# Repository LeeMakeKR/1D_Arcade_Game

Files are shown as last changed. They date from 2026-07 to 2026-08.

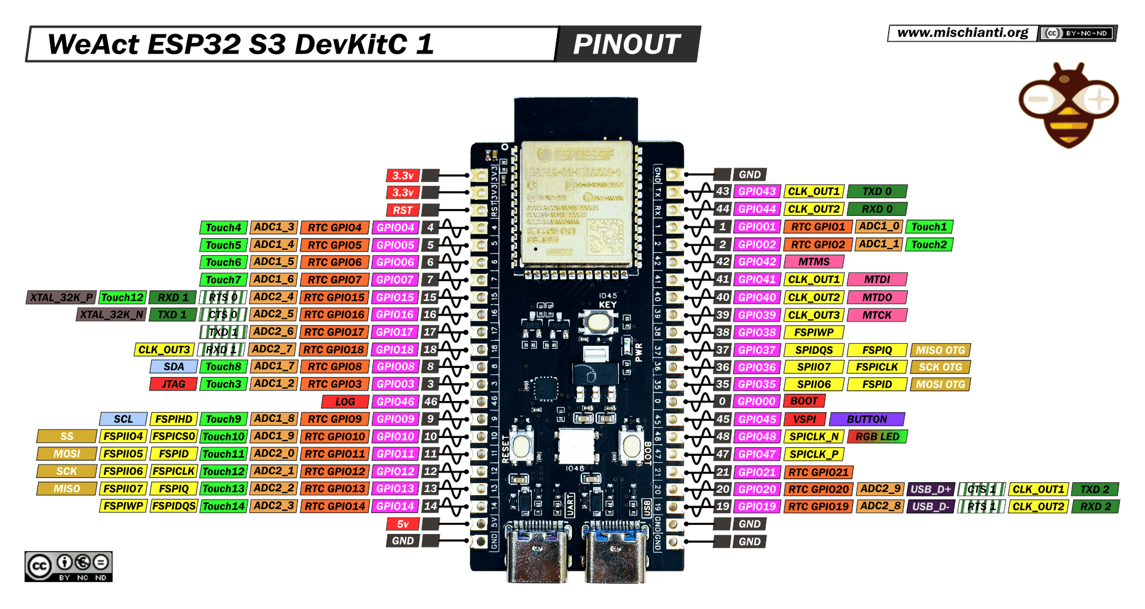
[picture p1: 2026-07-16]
pics/WeAct-esp32-S3-DevKitC-1-pinout-mischianti.png

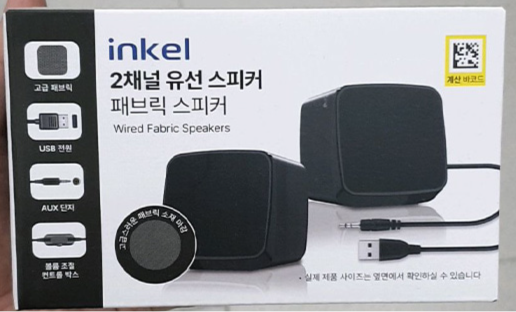
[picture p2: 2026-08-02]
pics/스크린샷 2026-08-02 133538.png

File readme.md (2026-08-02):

WS2815 line LED 를 사용한 1D arcade 게임기 제작 프로젝트

개요

3m 길이의 WS2815 라인 LED 172칸을 화면 삼아, 위치와 색만으로 게임을 표현하는 1차원 아케이드 게임기다
ESP32-S3 한 장에 아케이드 스위치 4개와 ST7735 LCD, I2S 앰프를 물려 입력·점수판·효과음을 함께 처리한다.
같은 펌웨어를 올린 보드 두 대를 ESP-NOW로 연결하면 2인 대전이 되고
수록 게임은 SNAKE INVADER / SOLO PONG / DUEL PONG 세 가지다.

[입력]

- 버튼1: GPIO7 - WS2815 LED 가 결합된 아케이드 스위치
- 버튼2: GPIO15 - WS2815 LED 가 결합된 아케이드 스위치
- 버튼3: GPIO16 - WS2815 LED 가 결합된 아케이드 스위치
- 버튼4: GPIO17 - WS2815 LED 가 결합된 아케이드 스위치
- 버튼5: GPIO18 - 토글 스위치, 선택에 따라 1p/2p 전환. 

미구현
- 조이스틱 X축 (아날로그, ADC1_CH3, 하드웨어 고정): GPIO4
- 조이스틱 Y축 (아날로그, ADC1_CH4, 하드웨어 고정): GPIO5
- 조이스틱 클릭 스위치 (디지털 입력): GPIO6

[출력]

- WS2815 데이터(DI): GPIO8
- WS2815 백업 데이터(BI): GPIO 연결 불필요 — 스트립 입구에서 GND에 연결(플로팅 금지)
- ST7735 TFT LCD (128x160, 4-wire SPI): RS(=DC) GPIO9, CS GPIO10(FSPI 하드웨어 기본 CS0), SDA(=MOSI) GPIO11(FSPI 하드웨어 기본 핀), CLK(=SCLK) GPIO12(FSPI 하드웨어 기본 핀), RST GPIO14, VCC 3.3V, GND GND
  - 모듈에 백라이트 핀(BLK/LED)이 따로 나와 있는 버전이면 3.3V에 연결한다.
  - 핀이 7개(VCC/GND/CLK/SDA/RS/RST/CS)뿐인 보드는 백라이트가 내부에서 VCC에 물려 있다.
  - VCC는 3.3V 권장. 레귤레이터가 실장된 모듈이라 5V도 받지만, 로직 레벨 시프터가 없는 모듈에 5V를 넣으면 3.3V 신호가 불안정해질 수 있다.
- I2S MAX98357A (앰프): BCLK GPIO42, LRCLK(WS) GPIO41, DOUT GPIO40
- 보드 간 통신: ESP-NOW 무선

핀아웃 다이어그램 (WeAct ESP32-S3 N16R8 DevKitC-1, mischianti 핀아웃 이미지 배치 기준)

```text
                                                     ┌─[ANT]──┐
                                      3V3            ●──┤        ├──●  GND
                                      3V3            ●──┤        ├──●  GPIO43         → (USB-UART TXD0, 사용금지)
                                      RST            ●──┤        ├──●  GPIO44         → (USB-UART RXD0, 사용금지)
           IN: 조이스틱 X (ADC1_CH3)  GPIO4          ●──┤        ├──●  GPIO1          → (예비 핀)
           IN: 조이스틱 Y (ADC1_CH4)  GPIO5          ●──┤        ├──●  GPIO2          → (예비 핀)
            IN: 조이스틱 클릭 스위치  GPIO6          ●──┤        ├──●  GPIO42         → OUT: I2S BCLK
                           IN: 버튼1  GPIO7          ●──┤        ├──●  GPIO41         → OUT: I2S LRCLK(WS)
                           IN: 버튼2  GPIO15         ●──┤        ├──●  GPIO40         → OUT: I2S DOUT
                           IN: 버튼3  GPIO16         ●──┤        ├──●  GPIO39         → (JTAG 예비핀, 미사용)
                           IN: 버튼4  GPIO17         ●──┤        ├──●  GPIO38         → (옥탈 PSRAM 내부용, 사용금지)
                           IN: 버튼5  GPIO18         ●──┤        ├──●  GPIO37         → (옥탈 PSRAM 내부용, 사용금지)
                    OUT: WS2815 DATA  GPIO8          ●──┤        ├──●  GPIO36         → (옥탈 PSRAM 내부용, 사용금지)
             (스트랩핀/JTAG, 미사용)  GPIO3          ●──┤        ├──●  GPIO35         → (옥탈 PSRAM 내부용, 사용금지)
                  (스트랩핀, 미사용)  GPIO46         ●──┤        ├──●  GPIO0          → (스트랩핀/BOOT, 미사용)
                     OUT: LCD RS(DC)  GPIO9          ●──┤        ├──●  GPIO45         → (스트랩핀/VDD_SPI, 미사용)
         OUT: LCD CS (FSPI 기본 CS0)  GPIO10         ●──┤        ├──●  GPIO48         → (온보드 WS2812 RGB LED 전용)
     OUT: LCD SDA/MOSI (FSPI 기본핀)  GPIO11         ●──┤        ├──●  GPIO47         → (예비 핀)
     OUT: LCD CLK/SCLK (FSPI 기본핀)  GPIO12         ●──┤        ├──●  GPIO21         → (예비 핀)
 (예비, FSPI MISO 기본핀·LCD 미사용)  GPIO13         ●──┤        ├──●  GPIO20         → (USB D-, 사용금지)
                        OUT: LCD RST  GPIO14         ●──┤        ├──●  GPIO19         → (USB D+, 사용금지)
                                      5V             ●──┤         ├──●  GND
                                      GND            ●──┤        ├──●  GND
                                                     └[UART]──[USB]┘
```

핀 선택 이유 / 특정 핀 사용 주의사항

1. 이 보드(N16R8)는 16MB 플래시 + 8MB 옥탈(Octal) PSRAM 구성으로, PSRAM용 추가 데이터 라인과 DQS 스트로브가 GPIO33~37에 내부 배선되어 있음. GPIO33/34는 아예 헤더로 나오지 않고, GPIO35/36/37은 헤더에 노출되어 있지만 실제로는 PSRAM 전용이라 GPIO로 재사용하면 PSRAM 접근이 깨져 보드가 멎을 수 있음 → 세 핀 모두 사용 금지. 같은 그룹에 인접한 GPIO38도 안전을 위해 예비로 비워둠.
2. 조이스틱 아날로그 입력(X/Y)은 ADC1 전용 핀(GPIO4/5)에 배치. ESP32-S3도 클래식 ESP32와 동일하게 Wi-Fi 활성 시 ADC2 정확도/사용 제한 이슈가 있어 ADC1이 안전함. 같은 조이스틱 신호인 클릭 스위치(GPIO6)도 바로 옆 핀에 배치.
3. GPIO0/3/45/46은 부팅 모드를 결정하는 스트랩핀(GPIO0: BOOT, GPIO3: JTAG 신호 소스 선택, GPIO45: VDD_SPI 전압 선택, GPIO46: ROM 메시지 출력 제어). 외부 소자가 부팅 순간 이 핀들의 전압을 강제로 바꾸면 오동작할 수 있어 미사용으로 비워둠.
4. GPIO43/44는 보드 내장 USB-UART 브릿지(별도 USB-C "UART" 포트)가 사용하는 UART0(TXD0/RXD0) 고정 핀이라 시리얼 모니터/펌웨어 업로드 용도로 남겨두고 다른 용도로 쓰지 않음. GPIO19/20은 칩 내장 네이티브 USB(D-/D+)로 "USB" 포트에 연결되어 있어 마찬가지로 비워둠.
5. GPIO48은 보드에 실장된 온보드 WS2812 RGB LED 전용 데이터 핀이라 외부 신호 용도로 재사용하지 않음. 외부 WS2815 라인은 별도 핀(GPIO8)을 사용.
6. LCD는 SCLK(GPIO12)/MOSI(GPIO11)/CS(GPIO10)를 FSPI(ESP32-S3 기본 SPI) 하드웨어 기본 핀 그대로 사용하는 것을 최우선으로 함(라이브러리 하드웨어 SPI 그대로 사용 가능하고, CS까지 기본 핀에 맞출 수 있어 이전 클래식 ESP32 설계보다 배선이 더 단순함). DC/RST는 자유 GPIO라 이 블록 양옆의 GPIO9/14에 배치했으며, FSPI MISO 기본핀(GPIO13)은 LCD가 읽기 신호를 쓰지 않아 예비 핀으로 남김. ST7735의 RS/SDA/CLK는 각각 DC/MOSI/SCLK와 같은 신호임. ST7735는 128x160x16bit라 전체 화면 한 장이 40KB이므로, SPI 클럭을 하드웨어 SPI 최대치(27~40MHz)로 올리고 화면 전체를 매번 다시 그리는 대신 바뀐 영역만 갱신하는 편이 좋음.
7. 버튼 5개(GPIO7/15/16/17/18)와 조이스틱(GPIO4/5/6)은 보드 좌측 헤더에서 RST 이후로 물리적으로 연속된 핀에 몰아서 배치해 배선을 단순화. 기능적 제약이 없는 핀이라 인접 배치를 우선 적용.
8. UART2(GPIO1/2)와 I2S(GPIO42/41/40)는 클래식 ESP32와 달리 ESP32-S3에서는 GPIO 매트릭스로 완전히 자유롭게 재배치 가능한 주변장치라 하드웨어로 고정된 핀이 아님. 남은 핀 중 보드 우측 헤더에서 서로 인접한 자리를 골라 배치했을 뿐 반드시 이 핀이어야 하는 것은 아님.
9. WS2815는 타이밍에 민감하므로 다른 기능과 공유하지 않는 GPIO8에 단독 배치 권장.
10. GPIO39(JTAG 예비), GPIO47, GPIO21은 하드웨어 제약이 없는 예비 핀으로 남겨둠.
12. 아두이노에서 컴파일 시 확인할 것.
- ESP32-S3 보드 선택
- FLASH SIZE: 16MB
- Partition Scheme: HUGE APP
- UPLOAD SPEED: 921600 으로 하면 실패하는 경우 있음. 115200으로. 

효과음 제작은 
https://sfxr.me/
에서 했으며 sounds.md 문서에 정리해 두었다.

BOM

WS2815
https://aliexpress.com/item/4001331197520.html
[3M 60 IP67]
- 1미터당 60개의 LED 가 배치되어 있으며 WS2815칩을 사용하여 12v를 그대로 사용할 수 있다. 
WS2812 는 테스트 결과 끝단 전압 강하로 추가로 전선 연결이 필요하여 제작이 번거롭다
3미터 총 180개의 LED를 사용하며, 스위치용으로 8개를 절단해 LED 스트립에는 172개를 사용한다

항공잭
https://aliexpress.com/item/1005008859055554.html
GX12, 5Pin, 5Sets (Male Female)
- 2pin 을 구매해도 됨
- 최초 통신 연결용으로 5핀을 사용했으나, ESPNOW 로 통신하게 되어 필요가 없어졌다. 전원공급 2선만 사용해도 충분하다

MAX98357A 사운드 모듈
https://aliexpress.com/item/1005012452360614.html

기타
xh connectors, 
wires

m3 insert nuts, bolts

speakers
-다이소에서 구매한 스피커를 사용했다

power jack
https://aliexpress.com/item/1005007327459848.html

power switch
https://ko.aliexpress.com/item/1005006151890626.html

arcade switch
구매했던 제품은 링크가 사라져 최대한 비슷한 제품을 링크한다
지름 30MM 에 투명한 제품이면 거의 사용 가능
https://ko.aliexpress.com/item/1005008769355244.html

tft lcd
https://aliexpress.com/item/1005012439751456.html
-ST7735 128x160 SPI 모듈 사용
이것도 링크가 사라져 비슷한 제품을 링크한 것인데 이런 류의 LCD 모듈은 제품마다 약간씩 화면 표시가 달라지는 경우가 있다. 
RED TAB, GREEN TAB, BLUE TAB 등으로 구분되며, RED TAB 이 가장 일반적이다.
화면이 이상하게 표시되면 TAB 색상을 확인하고, 라이브러리에서 해당 TAB에 맞는 초기화 코드를 사용해야 한다.

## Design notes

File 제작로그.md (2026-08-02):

# 제작 로그

## 2026-07-25

- 1P/2P 통신을 ESP-NOW로 변경
- LED를 WS2815로 변경
- 이에 따라 핀아웃 변경

## 2026-07-26

- 테스트 코드 정리

## 2026-07-30

### 사운드 테스트

sfxr로 만든 사운드 파라미터를 이용해 바로 재생할 수 있는지 검토해 보니,
미리 렌더링을 해서 PSRAM에 저장해 두고 재생하는 것도 가능함을 확인.

#### 부팅 시 프리렌더 PCM → PSRAM

- sfxr 파라미터를 부팅 때 한 번만 PCM으로 렌더 → PSRAM에 저장
- 런타임엔 믹서가 메모리 배열만 읽어 합산 → 합성 연산 0, I/O 0
- 동시 재생/멀티트랙에 이상적

부팅 시 렌더하는 경우 부팅 시간이 오래 걸리려나?

→ 일단 wav 파일을 그대로 사용하는 방법으로 진행하고,
재생 타이밍이 어긋나거나 안 맞는다면 이것도 같이 테스트해 보자.

→ 렌더된 PCM으로 테스트해 보니 멀티트랙 재생도 편하고 반응이 매우 즉각적.

### LCD 교체

NOKIA 5110 LCD → ST7735 LCD로 교체.
5110은 오래되어 열화된 데다, 두 기기 간 콘트라스트가 달라 화면이 깔끔하지 않은 문제가 있었음.

## 2026-08-01

- 부팅 로고 제작
- 2P 퐁 테스트
- 5V 전원 공급 문제로 7805 제거, DC-DC 모듈로 교체
- 각종 버그 수정. 
- 통합 코드 작성 및 테스트
- 로고 헤더 파일 용량 축소
- V1.0 릴리즈

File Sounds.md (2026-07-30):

powerup
- 동전을 먹거나 레벨업 하는 느낌의 긴 소리
{
  "oldParams": true,
  "wave_type": 1,
  "p_env_attack": 0,
  "p_env_sustain": 0.3499999940395355,
  "p_env_punch": 0,
  "p_env_decay": 0.3598533272743225,
  "p_base_freq": 0.256621778011322,
  "p_freq_limit": 0,
  "p_freq_ramp": 0.3860674798488617,
  "p_freq_dramp": 0,
  "p_vib_strength": 0,
  "p_vib_speed": 0,
  "p_arp_mod": 0,
  "p_arp_speed": 0,
  "p_duty": 1,
  "p_duty_ramp": 0,
  "p_repeat_speed": 0.4547119140625,
  "p_pha_offset": 0,
  "p_pha_ramp": 0,
  "p_lpf_freq": 1,
  "p_lpf_ramp": 0,
  "p_lpf_resonance": 0,
  "p_hpf_freq": 0,
  "p_hpf_ramp": 0,
  "sound_vol": 0.25,
  "sample_rate": 44100,
  "sample_size": 8
}
https://sfxr.me/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

laser
- 레이저 발사 느낌의 짧은 소리
{
  "oldParams": true,
  "wave_type": 2,
  "p_env_attack": 0,
  "p_env_sustain": 0.18799999356269836,
  "p_env_punch": 0.07099999487400055,
  "p_env_decay": 0.18399998545646667,
  "p_base_freq": 0.8160666823387146,
  "p_freq_limit": 0.07680398970842361,
  "p_freq_ramp": -0.39258667826652527,
  "p_freq_dramp": 0,
  "p_vib_strength": 0.09699999541044235,
  "p_vib_speed": 0,
  "p_arp_mod": 0,
  "p_arp_speed": 0,
  "p_duty": 0.4373622536659241,
  "p_duty_ramp": -0.42302313446998596,
  "p_repeat_speed": 0,
  "p_pha_offset": 0,
  "p_pha_ramp": 0,
  "p_lpf_freq": 1,
  "p_lpf_ramp": 0,
  "p_lpf_resonance": 0,
  "p_hpf_freq": 0.2832835018634796,
  "p_hpf_ramp": 0,
  "sound_vol": 0.25,
  "sample_rate": 44100,
  "sample_size": 8
}
https://sfxr.me/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

explosion01
- 폭발 느낌의 긴 소리
{
  "oldParams": true,
  "wave_type": 3,
  "p_env_attack": 0,
  "p_env_sustain": 0.2676795423030853,
  "p_env_punch": 0.7902796268463135,
  "p_env_decay": 0.3833795487880707,
  "p_base_freq": 0.5563449859619141,
  "p_freq_limit": 0,
  "p_freq_ramp": -0.3959657847881317,
  "p_freq_dramp": 0,
  "p_vib_strength": 0.1773683875799179,
  "p_vib_speed": 0.5040820837020874,
  "p_arp_mod": 0,
  "p_arp_speed": 0,
  "p_duty": 0,
  "p_duty_ramp": 0,
  "p_repeat_speed": 0.6476894021034241,
  "p_pha_offset": 0,
  "p_pha_ramp": 0,
  "p_lpf_freq": 1,
  "p_lpf_ramp": 0,
  "p_lpf_resonance": 0,
  "p_hpf_freq": 0,
  "p_hpf_ramp": 0,
  "sound_vol": 0.25,
  "sample_rate": 44100,
  "sample_size": 8
}
https://sfxr.me/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

explosion02
- 폭발 느낌의 긴 소리
{
  "oldParams": true,
  "wave_type": 3,
  "p_env_attack": 0,
  "p_env_sustain": 0.3994917869567871,
  "p_env_punch": 0.238620325922966,
  "p_env_decay": 0.44099998474121094,
  "p_base_freq": 0.05014554783701897,
  "p_freq_limit": 0,
  "p_freq_ramp": 0.048083990812301636,
  "p_freq_dramp": 0,
  "p_vib_strength": 0.66570645570755,
  "p_vib_speed": 0.2726331651210785,
  "p_arp_mod": 0,
  "p_arp_speed": 0,
  "p_duty": 0,
  "p_duty_ramp": 0,
  "p_repeat_speed": 0,
  "p_pha_offset": 0,
  "p_pha_ramp": 0,
  "p_lpf_freq": 1,
  "p_lpf_ramp": 0,
  "p_lpf_resonance": 0,
  "p_hpf_freq": 0,
  "p_hpf_ramp": 0,
  "sound_vol": 0.25,
  "sample_rate": 44100,
  "sample_size": 8
}
https://sfxr.me/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\

pickupCoin01
- 짧은 쇠를 두드리는 느낌의 띡 하는 소리
{
  "oldParams": true,
  "wave_type": 1,
  "p_env_attack": 0,
  "p_env_sustain": 0.02639184147119522,
  "p_env_punch": 0.45179933309555054,
  "p_env_decay": 0.1728859692811966,
  "p_base_freq": 0.8908432126045227,
  "p_freq_limit": 0,
  "p_freq_ramp": 0,
  "p_freq_dramp": 0,
  "p_vib_strength": 0,
  "p_vib_speed": 0,
  "p_arp_mod": 0.5362933278083801,
  "p_arp_speed": 0.5622999668121338,
  "p_duty": 0,
  "p_duty_ramp": 0,
  "p_repeat_speed": 0,
  "p_pha_offset": 0,
  "p_pha_ramp": 0,
  "p_lpf_freq": 1,
  "p_lpf_ramp": 0,
  "p_lpf_resonance": 0,
  "p_hpf_freq": 0,
  "p_hpf_ramp": 0,
  "sound_vol": 0.25,
  "sample_rate": 44100,
  "sample_size": 8
}
https://sfxr.me/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

pickupCoin02
- 띠링 하는 소리
{
  "oldParams": true,
  "wave_type": 1,
  "p_env_attack": 0,
  "p_env_sustain": 0.029718652367591858,
  "p_env_punch": 0.5886696577072144,
  "p_env_decay": 0.3078901767730713,
  "p_base_freq": 0.4670742154121399,
  "p_freq_limit": 0,
  "p_freq_ramp": 0,
  "p_freq_dramp": 0,
  "p_vib_strength": 0,
  "p_vib_speed": 0,
  "p_arp_mod": 0.44087502360343933,
  "p_arp_speed": 0.5607048869132996,
  "p_duty": 0,
  "p_duty_ramp": 0,
  "p_repeat_speed": 0,
  "p_pha_offset": 0,
  "p_pha_ramp": 0,
  "p_lpf_freq": 1,
  "p_lpf_ramp": 0,
  "p_lpf_resonance": 0,
  "p_hpf_freq": 0,
  "p_hpf_ramp": 0,
  "sound_vol": 0.25,
  "sample_rate": 44100,
  "sample_size": 8
}
https://sfxr.me/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
-snakeinvader에서 잘못된 총알을 snake가 맞았을 때
- 

blip01
- 삡 하는 짧은 소리
{
  "oldParams": true,
  "wave_type": 0,
  "p_env_attack": 0,
  "p_env_sustain": 0.12246111035346985,
  "p_env_punch": 0,
  "p_env_decay": 0.1764201670885086,
  "p_base_freq": 0.5056489706039429,
  "p_freq_limit": 0,
  "p_freq_ramp": 0,
  "p_freq_dramp": 0,
  "p_vib_strength": 0,
  "p_vib_speed": 0,
  "p_arp_mod": 0,
  "p_arp_speed": 0,
  "p_duty": 0.07392086088657379,
  "p_duty_ramp": 0,
  "p_repeat_speed": 0,
  "p_pha_offset": 0,
  "p_pha_ramp": 0,
  "p_lpf_freq": 1,
  "p_lpf_ramp": 0,
  "p_lpf_resonance": 0,
  "p_hpf_freq": 0.09999999403953552,
  "p_hpf_ramp": 0,
  "sound_vol": 0.25,
  "sample_rate": 44100,
  "sample_size": 8
}
https://sfxr.me/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

blip02
- 삡빕빕빕 하며 울리는 긴 소리
{
  "oldParams": true,
  "wave_type": 1,
  "p_env_attack": -0.00002966536339954473,
  "p_env_sustain": 0.5647220611572266,
  "p_env_punch": 0.6319263577461243,
  "p_env_decay": 0.4010697603225708,
  "p_base_freq": 0.7444775700569153,
  "p_freq_limit": 0,
  "p_freq_ramp": -0.16035959124565125,
  "p_freq_dramp": 0.7482393383979797,
  "p_vib_strength": -0.048199448734521866,
  "p_vib_speed": 0.8451669812202454,
  "p_arp_mod": 0.08687280863523483,
  "p_arp_speed": -0.3538631796836853,
  "p_duty": -0.1983754187822342,
  "p_duty_ramp": 0.16614454984664917,
  "p_repeat_speed": 0.31591108441352844,
  "p_pha_offset": -0.00942212250083685,
  "p_pha_ramp": 0.01845468580722809,
  "p_lpf_freq": 0.46619826555252075,
  "p_lpf_ramp": 0.939164400100708,
  "p_lpf_resonance": -0.1535068303346634,
  "p_hpf_freq": 0.021529486402869225,
  "p_hpf_ramp": -0.08147113025188446,
  "sound_vol": 0.25,
  "sample_rate": 44100,
  "sample_size": 8
}
https://sfxr.me/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

- 2p 시 사망 소리

fanfare
 - 승리 시 울리는 긴 소리

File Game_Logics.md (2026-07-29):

# 1D Arcade Game 로직 정리

## 공통 설계 원칙
- 게임 로직과 렌더링을 분리한다.
- 프레임버퍼 방식: 게임은 매 프레임 LED 배열(CRGB 배열)에 그리기만 수행하고, 렌더러가 고정 FPS(60~100Hz)로 스트립에 전송한다.
- WS2812 전송은 RMT 사용을 전제로 하며, 논블로킹으로 오디오/로직 영향 최소화.
- 1D 스프라이트/엔티티 공통 구조 사용: 위치(float), 길이, 색 패턴, 속도, 레이어.
- 렌더링 합성 순서: 배경 -> 오브젝트 -> 이펙트.
- 공통 게임 인터페이스: init() / update(dt, input) / render(buffer).
- 메인 루프는 고정 타임스텝으로 모든 게임 모드 공통 동작.
- 이벤트 시스템 분리: 게임은 HIT, SHOOT, BOUNCE 등 이벤트만 발생시키고, 사운드/SFX와 이펙트는 매니저가 처리.

### 통신 처리
- 2P 통신은 ESP-NOW 사용(배선 불필요, 지연 1~5ms 수준으로 타이밍 게임에 영향 없음).
- 1P/2P 역할 비대칭: 1P 보드가 게임 연산(물리/판정)과 LED 표시를 전담하는 authoritative, 2P 보드는 자기 스위치 입력을 이벤트로 감지해 ESP-NOW로 1P에 전달만 하고 연산/LED는 수행하지 않음.
- 1P는 자신의 로컬 입력과 2P로부터 수신한 스위치 이벤트를 동일하게 취급해 게임 로직을 진행.
- LCD는 양쪽 모두 동일하게 표시해야 하므로, 1P가 게임 정보/점수 등을 ESP-NOW로 2P에 전달하고 2P는 이를 받아 LCD만 갱신.
- 통신 방향 정리: 2P → 1P(스위치 이벤트), 1P → 2P(게임 상태·점수 표시용 정보).
- 채널 고정 + peer 등록 unicast 사용, 모뎀 슬립 비활성화(`esp_wifi_set_ps(WIFI_PS_NONE)`)로 지연 스파이크 방지.
- 페어링: 부팅 시 브로드캐스트(FF:FF:FF:FF:FF:FF)로 hello 패킷 교환 → 수신 콜백에서 상대 MAC을 peer로 등록 → 이후 unicast 통신.
- Wi-Fi 채널은 추후 설정 메뉴(LED 밝기/볼륨과 함께)에서 변경 가능하게 하고 NVS에 저장. 두 보드는 같은 채널이어야 통신됨.

## 1. 부팅 및 메뉴
- 5번 스위치로 모드 선택
- High: 1P
- Low: 2P
- 1P: 게임 메뉴 선택 및 설정 제어 가능.
- 2P: 1P의 선택을 따라 같은 게임 실행(자동 2P 모드 전환).

### 부팅 초기화
- LED 스트립 초기화
- 사운드 초기화
- 스위치 LED 점등
- LCD 초기화 및 표시
- 1P/2P 모드 감지 및 표시. 1p/2p 모드 감지 시 1P는 메뉴 선택 가능

### 게임 리스트 표시
1. Snake Invader
2. Pong

### 메뉴 조작
- 2번 스위치: Up
- 3번 스위치: Down
- 4번 스위치: Select
- 게임 시작 시 LCD에 3, 2, 1 카운트다운 표시

## 2. 게임 로직

### 2.1 Snake Invader
- 기본 스위치 색상
- 스위치 1: Blue
- 스위치 2: Green
- 스위치 4: Red

#### 진행 규칙
- 플레이어 반대쪽 끝에서 랜덤 색상의 Snake LED 출현.
- Snake 길이는 레벨에 비례해 증가.
- Snake 이동 속도도 레벨에 비례해 증가.
- 길이/속도는 디버깅용 변수로 조정 가능.

#### 공격 및 판정
- 스위치를 누르면 해당 색 총알 발사, 총알은 Snake 방향으로 이동(발사 사운드 재생).
- 총알이 Snake 선두에 닿고 색이 일치하면 선두 제거 + 점수 증가(사운드 재생).
- 색이 불일치하면 총알 제거, Snake는 가속되거나 꼬리 증가(사운드 재생).

#### 종료/클리어
- Snake 선두가 플레이어 끝에 닿으면 게임 오버.
- 게임 오버 시 점수를 LCD에 표시하고 Snake 제거(사운드 재생).
- Snake 길이가 0이면 웨이브 클리어, 다음 레벨 진행.
- 점수 계산식: 미정.

### 2.2 Pong
- 1~4번 스위치는 동일 역할.
- 모든 스위치는 White LED, 공도 White LED로 표시.
- 양쪽 끝에 대칭 영역 표시.
- 플레이어 쪽 기준 안쪽부터 Red 1개, Orange 2개, Yellow 3개, Green 5개.

#### 기본 진행
- 카운트다운 후 시작.
- 첫 공은 상대편에서 반드시 느린 속도로 발사.
- 공이 내 쪽 영역에 닿을 때 스위치를 누르면 반사 가능.

#### 반사 속도 규칙
- Green에서 반사: 느림
- Yellow에서 반사: 보통
- Orange에서 반사: 빠름
- Red에서 반사: 매우 빠름

#### 실점 및 재시작
- 공이 Red를 지나치면 실점.
- 실점한 쪽이 스위치를 눌러 재발사.
- 카운트다운 후 특정 스위치에 White LED 점등.
- 점등 후 빠르게 누를수록 발사 속도 증가.(테스트하여 시간을 조절할 것)
- 다른 스위치를 먼저 누르면 무조건 느리게 발사.

#### 1P CPU 규칙
- 1P 모드에서 상대는 CPU가 담당.
- CPU도 공이 자기 영역에 닿을 때 반사.
- CPU 결과 상태: Green, Yellow, Orange, Red, 실패.
- 저레벨: Green/실패 확률 높음.
- 고레벨: Red/Yellow 확률 높음.
- 레벨은 플레이어 점수에 따라 상승.
- 레벨이 오를수록 공 기본 속도 상승.

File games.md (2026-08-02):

# 1D Arcade Game — 게임 정리

## 1. 구현된 게임 (v1)

| 구분 | 게임 | 모듈 | 요약 |
|---|---|---|---|
| 1P | Snake Invader | `SnakeInvader.h` | 다가오는 멀티컬러 지렁이를 색 매칭 버튼으로 격추 |
| 1P | Solo Pong | `SoloPong.h` | 코트 끝 타격 영역에서 버튼으로 공을 반사, 친 위치에 따라 속도가 갈림 |
| 2P | Duel Pong | `DuelPong.h` | 보드 두 대를 ESP-NOW로 묶어 양 끝에서 공을 주고받는 대전 |

메뉴 표기는 `SNAKE` / `SOLO PONG` / `DUEL PONG`이다(LCD 폭 때문에 Snake Invader는 줄여 쓴다).

---

## 2. 구현된 게임 알고리즘

아래는 설계안이 아니라 현재 코드가 실제로 하는 일이다. 상수 이름은 각 모듈 헤더 상단의
`constexpr` 이름과 같다.

### 공통 구조

**모듈 규약** — 세 게임 모두 같은 세 함수만 노출하고, `1DarcadeV1.0.ino`가 이것만 부른다.
- `begin()` — 진입할 때 한 번. 상태 초기화
- `update(now)` — 매 loop마다. 게임 로직 + LED/LCD 갱신 (`now`는 `millis()`)
- `wantsExit()` — true가 되면 메뉴로 되돌린다
- Duel Pong만 `end()`가 추가로 있다(ESP-NOW 콜백/피어 정리)

**공유 계층은 `Arcade.h`뿐이다.** 스트립·LCD 객체, 스위치 입력(`Input::takePressed()`),
설정값(밝기/볼륨/ESP-NOW 채널), 색 유틸, 코트 좌표 계산(`depthFrom` / `zoneOfDepth` /
`zoneColor` / `halfOwner`)을 여기서 가져다 쓴다. 게임 로직 자체를 공유하는 프레임워크는 없다.

**그 외**
- 범용 1D 스프라이트 타입은 없다. 각 게임이 자기 상태를 직접 들고 있다.
- 이벤트 시스템도 없다. 소리는 게임이 판정한 자리에서 `soundPlay(SFX_*)`를 바로 부른다.
- 렌더는 게임이 `strip.setPixelColor()`로 직접 그리고 `safeShow()`로 내보낸다. 주기는
  `FRAME_MS`(16ms, 약 60FPS)이고, `show()`는 논블로킹이 아니라 176픽셀에 약 5.3ms 걸린다.
- 물리는 고정 타임스텝이 아니라 가변 dt다. 연출의 `delay()`로 프레임이 벌어졌을 때
  공이 튀지 않도록 dt를 0.05초로 잘라 쓴다.
- LCD는 프레임버퍼가 없어 한 장 전송에 약 14ms 걸리므로, 내용이 실제로 바뀐 순간에만 그린다.
- 코트는 라인 LED 172칸(인덱스 4~175)이고, 인덱스 0~3은 스위치 내장 LED다.

**타격 영역(두 퐁 공유, `Arcade.h`)** — 각 끝에서 안쪽으로 18칸.
자기 끝에서부터 빨강 3칸 / 노랑 6칸 / 초록 9칸.

### 2.1 Snake Invader

**상태**
- `snakeColors[]`: 세그먼트 색 배열. index 0 = 선두(플레이어에 가장 가까운 쪽), 최대 100칸
- `headPos`: float, 플레이어 방향으로 `snakeSpeed`씩 전진
- `bullets[8]`: `{ active, pos, color }`. 속도는 전부 `BULLET_SPEED`(150칸/초)로 같다

**루프**
1. 입력: 해금된 스위치 press → 그 스위치 색 총알 생성(`SFX_SHOOT`). 8발이 다 날아가는 중이면 조용히 버린다
2. 지렁이 전진(한 칸 넘어갈 때마다 `SFX_SNAKE_STEP`), 총알 전진
3. 충돌 판정: 총알 pos ≥ 선두 세그먼트 pos — 총알은 어느 쪽이든 소멸한다
   - 색 일치 → 선두 제거, **+10점**, `SFX_BULLET_HIT`
   - 색 불일치 → **지렁이 속도 ×1.15**(`SNAKE_MISS_ACCEL`), `SFX_BULLET_MISS`
4. 종료 판정
   - 길이 0 → 레벨 클리어(초록 2회 점멸) → 다음 레벨
   - `headPos` ≤ 코트 끝 → 게임 오버(빨강 3회 점멸). **레벨 1·0점으로 리셋**되고 READY 화면으로 돌아간다

**레벨 곡선**

| 항목 | 값 |
|---|-----|
| 길이 | `5 + (레벨-1) × 3`칸, 상한 100 (레벨 33부터 고정) |
| 속도 | `6.0 + (레벨-1) × 1.0`칸/초, 상한 60 |

**색 규칙** — 스위치 색은 위치 순서대로 Red / Green / Blue / White.
- 레벨 1~9: 흰색 스위치는 꺼지고 눌러도 발사되지 않으며, 지렁이에도 흰색이 섞이지 않는다(3색)
- 레벨 10: 흰색 해금 스윕 연출 후부터 4색
- 레벨 20+: 매 레벨 시작 전 4색을 스위치에 무작위 재배정(Fisher-Yates)

레벨 시작 연출은 셋 중 하나다. 흰색 해금(레벨 10) / 색 셔플 점멸(레벨 20+) /
3-2-1-GO 카운트다운(그 외). 연출 구간은 원본 타이밍을 그대로 옮기려고 `delay()`로 막고 진행한다.

### 2.2 Solo Pong

**상태**
- `ballPos` / `ballSpeed` / `ballDir`(+1 = CPU 쪽, -1 = 플레이어 쪽)
- 플레이어 영역 = 코트 인덱스가 작은 쪽 끝 18칸, CPU 영역 = 반대쪽 끝 18칸

**루프**
1. 공 이동: `ballPos += ballDir * ballSpeed * dt`
2. 플레이어 판정: 공이 자기 쪽으로 오는 중이고 자기 영역 안에 있을 때 아무 스위치나 누르면 반사.
   영역 밖에서 누르면 헛스윙으로 아무 일도 없다(페널티 없음)
3. CPU 판정: 확률로 반사하는 게 아니라, 공이 자기 영역에 들어온 순간 **"언제 스윙할지"를 한 번 정하고**
   그 시각에 스윙한다. 그때 공이 이미 지나갔으면 놓친 것이다 — 미스는 주사위가 아니라 느린 반응의 결과다.
   공이 빠를수록 영역 통과 시간이 짧아져 같은 반응으로도 더 자주 놓친다
   (18칸 통과 시간: 서브 60칸/초 → 300ms, 100칸/초 → 180ms, 상한 220칸/초 → 82ms)
4. 공이 코트 밖으로 나가면 반대쪽 득점

**반사 속도** — 친 위치(영역 안에서 공이 어디까지 들어왔는지)로 결정된다. 연속적인 정확도 값이 아니다.

| 친 위치 | 배율 | 비고 |
|---|---|---|
| 초록(가장 일찍, 안쪽 9칸) | ×1.00 | 속도 유지 |
| 노랑(중간 6칸) | ×1.18 | **가장 크게 가속** |
| 빨강(아슬아슬, 끝 3칸) | ×1.10 | 최저 85칸/초 보장 |

상한은 220칸/초. **CPU의 리턴은 속도를 바꾸지 않는다** — 랠리를 가속하는 건 플레이어의 타이밍뿐이다.
공은 항상 흰색 1칸이고(빠를 때 잔상을 남긴다), 색이 바뀌지는 않는다. 코트에 그려지는 색은 타격 영역 표시다.

**서브** — 1인용이라 서브권 교대가 없다. 항상 코트 중앙에서 플레이어 쪽으로 60칸/초로 출발한다.

**승패** — 라이프 개념은 없다. 플레이어가 5점을 먼저 내면 레벨 클리어(레벨 상한 없음),
CPU가 5점을 먼저 내면 게임 오버(레벨 1부터 다시).

**CPU 난이도** — 레벨이 오를수록 세 값이 같은 모양으로 깎인다(`rampDown`).

| 파라미터 | 레벨 1 | 레벨당 | 최소 |
|---|---|---|---|
| 반응 지연 | 120ms | -10ms | 20ms |
| 반응 흔들림(±) | 60ms | -5ms | 8ms |
| 무반응 확률 | 20% | -2%p | 2% |

### 2.3 Duel Pong

공 물리와 반사 규칙(영역 18칸, 초록/노랑/빨강 배율, 상한 220)은 Solo Pong과 같은 값이지만,
**코드를 공유하지는 않는다.** 두 모듈이 각자 상수와 `reflectSpeed()` / `drawBall()` /
`drawZones()` / `drawHalves()`를 따로 들고 있고, 실제로 공유하는 것은 `Arcade.h`의
좌표·존 계산 헬퍼뿐이다.

**보드 두 대** — 이 게임만 하드웨어가 두 대다.
- 라인 LED가 물려 있는 보드가 **1P이자 authoritative**다. 공 물리·판정·점수·사운드를 혼자
  결정하고 코트를 그린다. 반대 보드는 2P로, 자기 입력을 보내고 받은 상태를 LCD에 그린다
- 역할은 `BOARD_ID_PIN`(5번 토글)으로 정해지고 `begin()`에서 매번 다시 읽으므로 재부팅 없이 바뀐다
- 두 보드가 같은 역할이면 LCD에 `ROLE MISMATCH`가 뜬다
- 페어링 전에는 브로드캐스트 HELLO를 500ms마다 뿌리며 서로를 찾는다(`SEARCHING...`)

**패킷** — `MSG_HELLO` / `MSG_HELLO_ACK` / `MSG_INPUT`(2P→1P) / `MSG_STATE`(1P→2P, 120ms 주기 +
변화 시 즉시) / `MSG_SFX`(1P→2P). 소리를 1P가 판정해 내려보내는 이유는, 2P가 눌렀을 때 그게
유효한 반사인지 헛스윙인지는 1P만 알기 때문이다.

**소리 분리** — 자기 행동의 결과만 자기 쪽에서 들린다.
READY 누름 / 반사 / 놓침은 그 사람만, 준비 완료 / 카운트다운 / START / 서브는 양쪽에서 난다.

**진행**
- 양쪽이 다 READY를 눌러야 시작한다(`OK!` → 3-2-1 카운트다운 → `START`)
- 자기 쪽으로 오는 공만 받아칠 수 있다(방금 친 공을 되받는 것을 막는다). 영역 밖 press는 헛스윙
- **10점 선취 승리**. 첫 서브 방향은 무작위이고, 이후로는 **점수를 잃은 쪽으로** 서브한다(교대가 아니다)
- 점수는 LCD에만 표시한다. 라인 LED는 득점 시 코트 절반을 초록/빨강으로 나눠 보여준다
- 승리 화면은 두 보드가 서로 다른 글자를 띄우고(`YOU WIN` / `YOU LOSE`), 5초 뒤 무지개로 바뀐다

---

## 3. 개발 예정 (백로그)

### Solo
- Line Wobbler — 조이스틱 이동 + 흔들기 공격, 장애물 회피 (조이스틱 필요)
- 타이밍 스톱 — 왕복 LED를 목표 존에서 정지, 성공할수록 존 축소
- 반응속도 테스트 — 무작위 점등 후 반응 시간을 LED 길이로 표시
- 회피 러너 — 접근 장애물을 점프 버튼으로 회피 (1D 공룡 게임)
- 두더지 잡기 — 무작위 위치 색 점멸, 해당 색 버튼을 시간 내 타격
- 총알 지옥 — 양방향 접근 적을 색상 매칭 격추 (Snake 확장판)
- 리듬 게임 = 버튼 입력 타이밍에 따라 LED 점멸, 정확도에 따라 점수/콤보
- flappy bird — 버튼으로 , 장애물 회피

### 퍼즐/두뇌
- Simon Says — 색 순서 기억 후 입력, 점점 길어짐
- 1D 테트리스/스택 — 접근 블록을 타이밍 맞춰 쌓기, 어긋난 만큼 잘림
- 색 합성 퍼즐 — 색 혼합(R+G=노랑)으로 목표 색 생성
- 금고 털기 — 순환 LED를 특정 위치에 연속 정지

### 캐주얼
- 1D 룰렛/슬롯 — 감속 회전 LED 정지 위치 + 베팅
- 줄다리기 vs CPU — 연타로 표시등 끌어오기
- 폭탄 돌리기(솔로) — 가속 타이머, 조작 성공 시 시간 연장

### Duel
- 줄다리기 — 양쪽 연타로 경계선 밀기 (구현 최간단)
- 반응속도 대결 — 먼저 누른 쪽 승, 페이크 신호 감점
- 1D 격투 — 이동/공격/가드/대시, 사거리·타이밍 싸움
- 영역 전쟁 — 자기 색으로 칠하며 점유율 승부
- 스네이크 대전 — 같은 라인에서 먹이 경쟁
- 폭탄 돌리기(핫포테이토) — 타이밍 반사, 폭발 시 패배
- 동시 슈팅 대전 — 상호 총알 발사, 색 매칭 요격
 시간마다 쌓이는 tick을 이용해서 총알을 발사하고, 상대방의 색과 같은 색의 총알을 발사해서 맞추면 tick을 번다던가 하는 식으로 전략을 만들 수 있을 것 같다. 
- 리듬 배틀 — 동일 패턴 동시 플레이, 정확도로 방해 요소 전송
- Simon 대전 — 번갈아 시퀀스 추가, 먼저 틀린 쪽 패배
- 결투(서부극) — 무작위 딜레이 후 먼저 쏘는 쪽 승, 3판 2선승

### 시스템/부가
- 아이템 드롭(속도 감소, 라인 확장), 보스전(체력바), 콤보 배율
- 하이스코어: LED 바 그래프 + NVS 저장 (설정값 저장은 이미 `Settings`로 들어가 있으니 같은 자리에 붙이면 된다)
- 어트랙트 모드: 대기 중 레인보우 데모 — Snake READY 화면에 5초 무입력 시 동작하도록 들어가 있다. 메뉴 전체로 넓히는 것이 남았다
- 입력 다양화: 가속도계(흔들기), 로터리 엔코더, 조이스틱

---

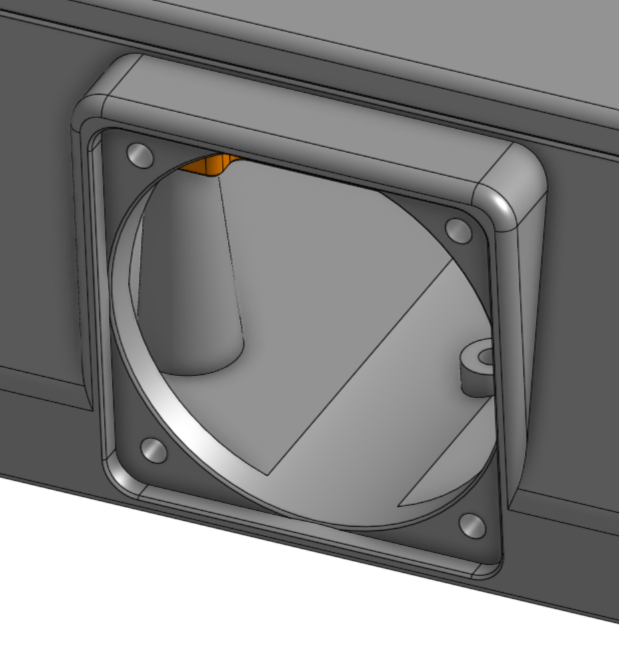
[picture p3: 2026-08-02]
pics/스크린샷 2026-08-02 130748.png

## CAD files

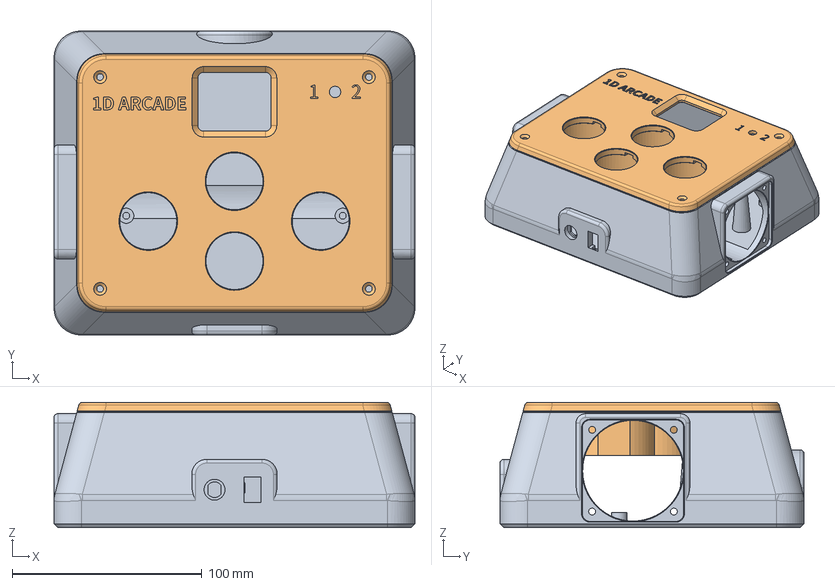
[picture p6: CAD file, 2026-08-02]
CAD/Box.step
190.0 x 160.0 x 66.0 mm

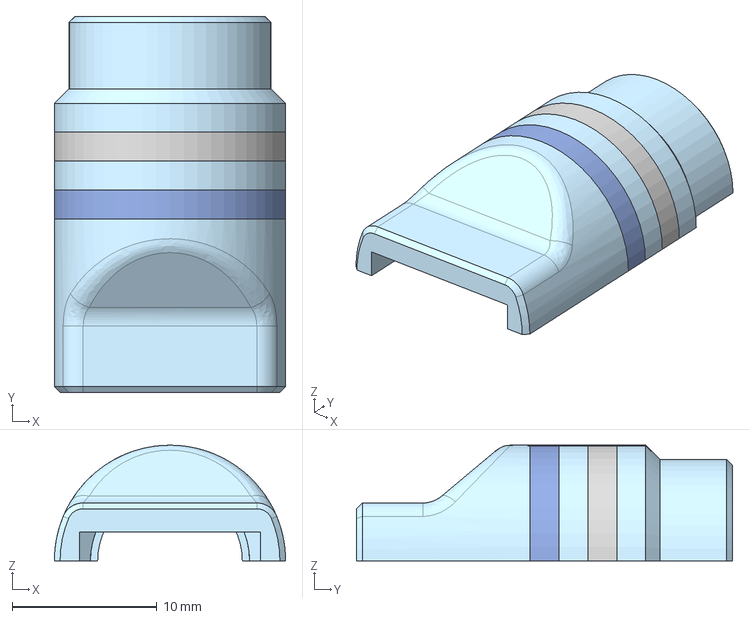
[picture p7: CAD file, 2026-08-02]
CAD/Connector_Cover_2stripe.step
16.0 x 26.0 x 8.00 mm

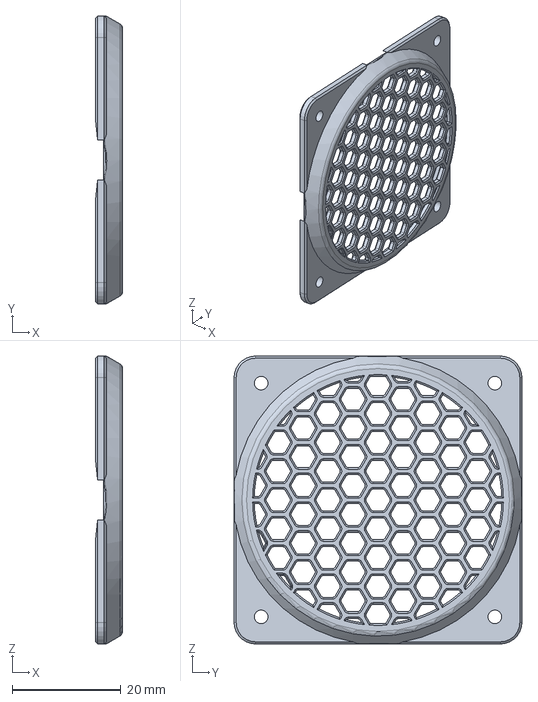
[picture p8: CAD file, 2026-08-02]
CAD/Speaker_Cover.step
5.00 x 53.0 x 53.0 mm

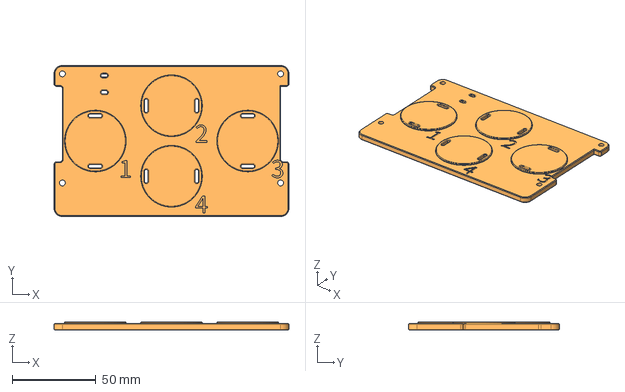
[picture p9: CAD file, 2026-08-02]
CAD/Switch_Cover.step
140.0 x 90.0 x 5.00 mm

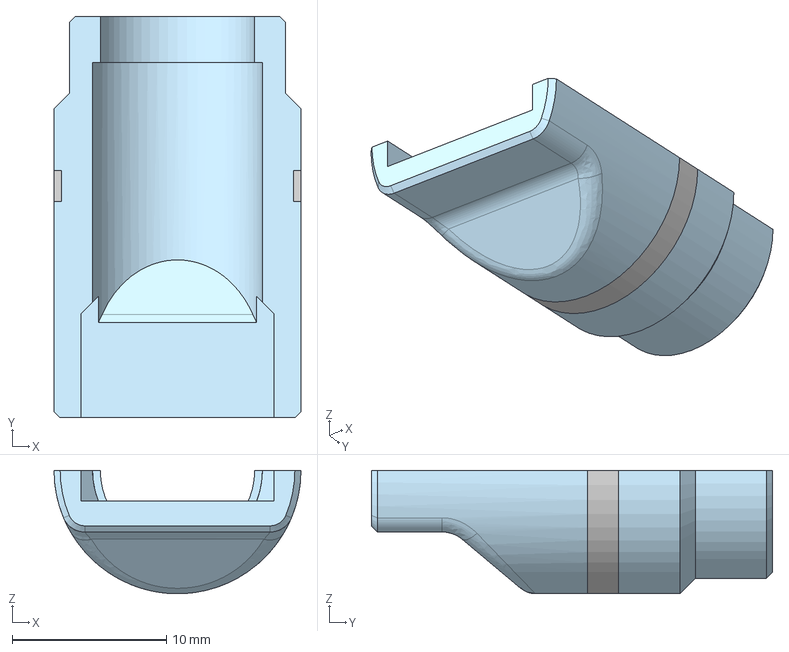
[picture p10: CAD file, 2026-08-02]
CAD/Connector_Cover_1stripe.step
16.0 x 26.0 x 8.00 mm

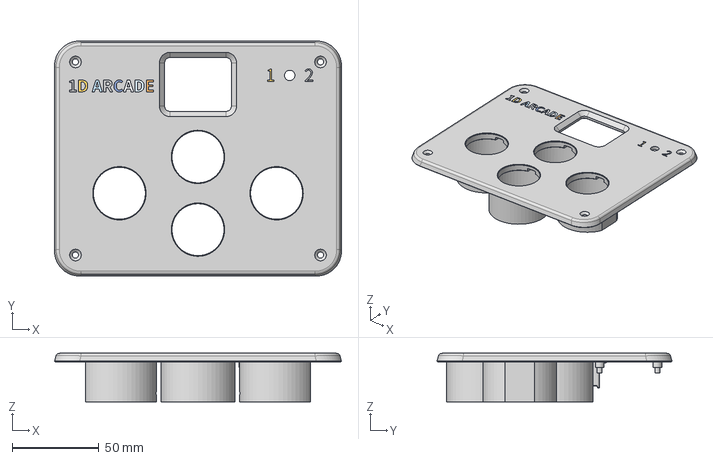
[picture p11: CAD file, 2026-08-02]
CAD/Box_Cover.step
165.7 x 135.7 x 28.0 mm

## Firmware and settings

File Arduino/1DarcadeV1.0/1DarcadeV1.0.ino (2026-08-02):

/*
  ===========================================================================
  1D Arcade V1.0 - 통합 스케치
  ===========================================================================
  지금까지의 테스트 코드를 하나로 묶은 본체다. 부팅 → 로고 → 메뉴 → 게임 순으로 돌고,
  게임에서 나오면 다시 메뉴로 돌아온다.

  이 파일이 하는 일은 구조뿐이다.
    - 하드웨어 초기화
    - 메뉴 상태 기계(게임 고르기 / 설정)
    - 고른 게임 모듈을 돌리고, 나가겠다고 하면 메뉴로 되돌리기
  게임 로직은 전부 헤더로 분리되어 있다.
    SnakeInvader.h / SoloPong.h / DuelPong.h
  공용 하드웨어·입력·설정·좌표 계산은 Arcade.h에 있다.

  ---------------------------------------------------------------------------
  버튼
  ---------------------------------------------------------------------------
    1번 Red    뒤로 / 메뉴로 나가기
    2번 Green  위로
    3번 Blue   선택
    4번 White  아래로
  게임 안에서는 네 버튼이 게임 나름의 역할을 하지만, Red는 어디서나 "메뉴로"다.

  ---------------------------------------------------------------------------
  메뉴
  ---------------------------------------------------------------------------
    MAIN ─┬─ GAME ─┬─ 1P ─┬─ SNAKE INVADER
          │        │      └─ SOLO PONG
          │        └─ 2P ── DUEL PONG
          └─ SETUP ─┬─ LED BRIGHTNESS
                    ├─ SOUND VOLUME
                    └─ ESP-NOW CHANNEL
  설정 항목은 Blue로 편집에 들어가 Green/White로 값을 올리고 내린다. 다시 Blue나 Red를
  누르면 편집이 끝나면서 값이 NVS에 저장되어 다음 부팅에도 유지된다. 편집 중에는 라인 LED가
  값을 같이 보여준다. 밝기는 스트립 전체가 무지개로 돌아 실제 밝기를 그대로 보여주고,
  볼륨은 파란 막대, 채널은 번호만큼의 노란 덩어리다.

  채널(1~13)은 Duel Pong의 ESP-NOW가 쓰는 값이라 두 보드가 같아야 서로 보인다. 주변
  공유기와 겹쳐 2P 연결이 불안할 때 옮기라고 빼 둔 항목이고, 1P 게임에는 영향이 없다.

  ---------------------------------------------------------------------------
  보드 두 대
  ---------------------------------------------------------------------------
  같은 펌웨어를 두 보드에 올린다. BOARD_ID_PIN(5번 토글)이 라인 LED가 달린 보드인지를
  나타내고, 그 값이 Duel Pong의 1P/2P 역할이 된다. 토글은 Duel Pong에 들어갈 때마다
  다시 읽으므로 재부팅 없이 역할을 바꿀 수 있다. 현재 상태는 메인 메뉴에 표시된다.
  렌더링은 이 값을 보지 않고 늘 스트립 전체를 그린다(Arcade.h의 hasLineLeds 주석 참고).

  ---------------------------------------------------------------------------
  보드 설정 (Tools 메뉴)
  ---------------------------------------------------------------------------
    - Board: ESP32S3 Dev Module
    - Partition Scheme: "Huge APP (3MB No OTA/1MB SPIFFS)"
      (세 게임의 사운드와 로고가 모두 들어가고 WiFi 스택까지 얹히므로 기본값으로는 빠듯하다)
  ===========================================================================
*/

#include "Arcade.h"

// 사운드 헤더는 PCM 배열 정의를 담고 있어서 이 .ino 한 곳에서만 include한다.
#include "sounds/blip01.h"
#include "sounds/blip02.h"
#include "sounds/laser.h"
#include "sounds/pickupCoin01.h"
#include "sounds/pickupCoin02.h"
#include "sounds/explosion01.h"
#include "sounds/explosion02.h"
#include "sounds/powerUp.h"
#include "sounds/fanfare.h"

// Arcade.h의 SfxId 순서와 정확히 같아야 한다.
static const SoundClip* const GAME_SOUNDS[NUM_SFX] = {
  &CLIP_blip01,        // SFX_UI_MOVE
  &CLIP_pickupCoin02,  // SFX_UI_SELECT
  &CLIP_blip02,        // SFX_UI_BACK
  &CLIP_powerUp,       // SFX_READY_BOTH
  &CLIP_blip01,        // SFX_COUNTDOWN
  &CLIP_blip02,        // SFX_START
  &CLIP_pickupCoin02,  // SFX_SERVE
  &CLIP_pickupCoin01,  // SFX_HIT_GREEN
  &CLIP_pickupCoin02,  // SFX_HIT_YELLOW
  &CLIP_blip01,        // SFX_HIT_RED
  &CLIP_laser,         // SFX_CPU_HIT
  &CLIP_explosion02,   // SFX_MISS
  &CLIP_pickupCoin02,  // SFX_MISS_OPPONENT
  &CLIP_laser,         // SFX_SHOOT
  &CLIP_explosion01,   // SFX_BULLET_HIT
  &CLIP_blip02,        // SFX_BULLET_MISS
  &CLIP_pickupCoin01,  // SFX_SNAKE_STEP
  &CLIP_powerUp,       // SFX_LEVEL_CLEAR
  &CLIP_fanfare,       // SFX_WIN
  &CLIP_explosion01    // SFX_GAME_OVER
};

// 게임 모듈은 Arcade.h와 사운드 표가 준비된 뒤에 include한다.
#include "SnakeInvader.h"
#include "SoloPong.h"
#include "DuelPong.h"

// ---------------------------------------------------------------------------
// 앱 상태
// ---------------------------------------------------------------------------
enum App : uint8_t { APP_MENU, APP_SNAKE, APP_SOLO, APP_DUEL };
App app = APP_MENU;

enum Page : uint8_t { P_MAIN, P_MODE, P_LIST_1P, P_LIST_2P, P_SETUP };
Page page = P_MAIN;

uint8_t cursor = 0;          // 현재 페이지의 커서 위치
bool editing = false;        // 설정 페이지에서 값 편집 중인가
bool menuDirty = true;       // LCD를 다시 그려야 하는가
uint32_t lastMenuFrameMs = 0;

// 페이지별 항목. 화면 그리기와 커서 범위를 한 곳에서 얻기 위해 표로 둔다.
//
// 항목 이름 길이 제한: 크기 2 글자는 12px이고 x=8에서 커서(">")까지 붙여 그리므로
// 화면 160px에 들어가려면 이름이 최대 11자다. 설정 페이지는 오른쪽에 값을 같이 그려서
// (SETTING_VALUE_X) 더 짧아야 한다. 이름은 games.md의 정식 표기를 따른다.
struct PageDef {
  const char* title;
  const char* items[3];
  uint8_t count;
};

const PageDef PAGES[] = {
  { "1D ARCADE", { "GAME",  "SETUP", nullptr }, 2 },   // P_MAIN
  { "GAME",      { "1P",    "2P",    nullptr }, 2 },   // P_MODE
  { "1 PLAYER",  { "SNAKE", "SOLO PONG", nullptr }, 2 },   // P_LIST_1P
  { "2 PLAYER",  { "DUEL PONG", nullptr, nullptr }, 1 },   // P_LIST_2P
  { "SETUP",     { "BRIGHT", "VOLUME", "CHANNEL" }, 3 },   // P_SETUP
};

// 설정 값 숫자를 그리는 x. 이름이 여기까지 침범하지 않도록 위 길이 제한을 지킬 것.
#define SETTING_VALUE_X  (LCD_W - 28)

// 밝기 조절 중에 스트립 전체를 채우는 무지개.
// 감쇠를 게임의 전체 점등 연출과 같은 0.25로 맞췄다. 여기서 보이는 밝기가 곧 게임에서
// 코트 전체가 켜질 때의 밝기라 미리보기가 정직해지고, 172칸을 세 채널로 켜는
// 가장 무거운 화면이라 전류도 같이 눌러진다.
#define MENU_RAINBOW_PERIOD_MS  4000
#define MENU_RAINBOW_SCALE      0.25f

// 채널 조절 중에 라인 LED에 그리는 덩어리. 최대 13개가 172칸 안에 넉넉히 들어간다(13*6 = 78).
#define CHANNEL_DOT_PITCH  6   // 덩어리 시작 사이의 간격(칸)
#define CHANNEL_DOT_LEN    2   // 덩어리 하나의 길이(칸)

// ---------------------------------------------------------------------------
// 메뉴 그리기
// ---------------------------------------------------------------------------
void drawMenuLcd() {
  const PageDef& p = PAGES[page];

  display.clearDisplay();
  display.setTextColor(ST77XX_CYAN);
  printCentered(p.title, 2, 4);
  display.drawFastHLine(0, 24, LCD_W, LCD_GREY);

  for (uint8_t i = 0; i < p.count; i++) {
    int16_t y = 34 + i * 26;
    bool sel = (i == cursor);

    if (sel) display.fillRect(0, y - 4, LCD_W, 24, editing ? 0x0208 : 0x2104);

    display.setTextSize(2);
    display.setTextColor(sel ? ST77XX_WHITE : LCD_GREY);
    display.setCursor(8, y);
    display.print(sel ? ">" : " ");
    display.print(p.items[i]);

    // 설정 페이지는 항목 오른쪽에 현재 값을 같이 보여준다
    if (page == P_SETUP) {
      uint8_t v = (i == 0) ? settingBrightness
                : (i == 1) ? settingVolume
                :            settingChannel;
      display.setTextColor(sel ? ST77XX_YELLOW : LCD_GREY);
      display.setCursor(SETTING_VALUE_X, y);
      display.print(v);
    }
  }

  // 메인 화면에는 5번 토글 상태를 같이 보여준다. Duel Pong의 1P/2P가 여기서 갈리는데,
  // 게임에 들어가기 전에는 확인할 방법이 없어서 토글이 죽어도 알아채지 못한다.
  if (page == P_MAIN) {
    display.setTextSize(1);
    display.setTextColor(LCD_GREY);
    display.setCursor(LCD_W - 58, 100);
    display.print("BOARD: ");
    display.print(readBoardIsMain() ? "1P" : "2P");
  }

  display.setTextColor(LCD_GREY);
  if (page == P_SETUP && editing) printCentered("GRN/WHT:ADJUST  BLU:OK", 1, 116);
  else if (page == P_MAIN)        printCentered("GRN/WHT:MOVE  BLU:SELECT", 1, 116);
  else                            printCentered("BLU:SELECT  RED:BACK", 1, 116);

  display.display();
}

void drawMenuStrip(uint32_t now) {
  // 밝기를 조절하는 동안에는 스트립 전체(스위치 LED 포함)를 무지개로 돌린다.
  // 값을 막대로 보여주는 것보다, 세 채널이 다 켜진 화면을 직접 보는 편이 밝기 판단에 낫다.
  // 값 자체는 LCD 숫자로 확인할 수 있다.
  if (page == P_SETUP && editing && cursor == 0) {
    drawRainbow(now, MENU_RAINBOW_PERIOD_MS, MENU_RAINBOW_SCALE);
    safeShow();
    return;
  }

  strip.clear();
  drawMenuSwitchLeds();

  if (page == P_SETUP && editing && cursor == 1) {
    // 볼륨은 귀로 듣는 값이라 눈으로 볼 게 없어서, 라인 LED에 값을 막대로 보여준다.
    int16_t n = (int16_t)((uint32_t)FIELD_LEN * settingVolume / SETTING_STEPS);
    for (int16_t i = 0; i < n; i++) {
      strip.setPixelColor(FIELD_START + i, scaleColor(colBlue(), 0.35f));
    }
  } else if (page == P_SETUP && editing && cursor == 2) {
    // 채널은 비율이 아니라 번호라서 막대로는 몇 번인지 읽히지 않는다. 띄엄띄엄 놓은
    // 덩어리 N개로 그려서 두 보드를 나란히 놓고 눈으로 세어 맞출 수 있게 한다.
    for (uint8_t c = 0; c < settingChannel; c++) {
      for (uint8_t d = 0; d < CHANNEL_DOT_LEN; d++) {
        int16_t idx = FIELD_START + c * CHANNEL_DOT_PITCH + d;
        if (idx > FIELD_END) break;
        strip.setPixelColor(idx, scaleColor(colYellow(), 0.35f));
      }
    }
  }
  safeShow();
}

// ---------------------------------------------------------------------------
// 메뉴 동작
// ---------------------------------------------------------------------------
void gotoPage(Page p) {
  page = p;
  cursor = 0;
  editing = false;
  menuDirty = true;
}

void startGame(App a) {
  app = a;
  switch (a) {
    case APP_SNAKE: SnakeInvader::begin(); break;
    case APP_SOLO:  SoloPong::begin();     break;
    case APP_DUEL:  DuelPong::begin();     break;
    default: break;
  }
}

void returnToMenu() {
  if (app == APP_DUEL) DuelPong::end();   // ESP-NOW 콜백/피어 정리
  app = APP_MENU;
  Input::flush();
  applyBrightness();   // 게임이 밝기를 건드렸을 수 있으니 설정값으로 되돌린다
  menuDirty = true;
}

// 현재 페이지에서 Blue(선택)를 눌렀을 때.
void menuSelect() {
  switch (page) {
    case P_MAIN:
      soundPlay(SFX_UI_SELECT);
      gotoPage(cursor == 0 ? P_MODE : P_SETUP);
      break;

    case P_MODE:
      soundPlay(SFX_UI_SELECT);
      gotoPage(cursor == 0 ? P_LIST_1P : P_LIST_2P);
      break;

    case P_LIST_1P:
      soundPlay(SFX_UI_SELECT);
      startGame(cursor == 0 ? APP_SNAKE : APP_SOLO);
      break;

    case P_LIST_2P:
      soundPlay(SFX_UI_SELECT);
      startGame(APP_DUEL);
      break;

    case P_SETUP:
      soundPlay(SFX_UI_SELECT);
      editing = !editing;            // Blue로 편집에 들어가고 Blue로 나온다
      if (!editing) Settings::save();  // 값이 확정되는 지점
      menuDirty = true;
      break;
  }
}

// 현재 페이지에서 Red(뒤로)를 눌렀을 때.
void menuBack() {
  if (page == P_SETUP && editing) {
    editing = false;
    Settings::save();              // Red로 빠져나와도 되돌리기는 없으므로 그대로 확정한다
    soundPlay(SFX_UI_BACK);
    menuDirty = true;
    return;
  }

  switch (page) {
    case P_MAIN:                              break;   // 최상단이라 갈 곳이 없다
    case P_MODE:
    case P_SETUP:     soundPlay(SFX_UI_BACK); gotoPage(P_MAIN); break;
    case P_LIST_1P:
    case P_LIST_2P:   soundPlay(SFX_UI_BACK); gotoPage(P_MODE); break;
  }
}

// 편집 중이면 값을, 아니면 커서를 움직인다. delta: +1 = 위/증가, -1 = 아래/감소.
void menuMove(int8_t delta) {
  if (page == P_SETUP && editing) {
    // 밝기/볼륨은 0~SETTING_STEPS 단계지만 채널은 번호 그대로라 범위가 다르다.
    uint8_t& v = (cursor == 0) ? settingBrightness
               : (cursor == 1) ? settingVolume
               :                 settingChannel;
    int16_t lo = (cursor == 2) ? CHANNEL_MIN : 0;
    int16_t hi = (cursor == 2) ? CHANNEL_MAX : SETTING_STEPS;

    int16_t nv = (int16_t)v + delta;
    if (nv < lo) nv = lo;
    if (nv > hi) nv = hi;
    if ((uint8_t)nv == v) return;
    v = (uint8_t)nv;

    if      (cursor == 0) applyBrightness();
    else if (cursor == 1) applyVolume();
    else                  applyChannel();
    Settings::markDirty();
    soundPlay(SFX_UI_MOVE);   // 볼륨은 이 소리로 바뀐 크기를 바로 확인할 수 있다
    menuDirty = true;
    return;
  }

  const PageDef& p = PAGES[page];
  if (p.count <= 1) return;
  int8_t nc = (int8_t)cursor - delta;              // 위로가 인덱스 감소
  if (nc < 0) nc = (int8_t)p.count - 1;            // 끝에서 반대편으로 감는다
  if (nc >= (int8_t)p.count) nc = 0;
  cursor = (uint8_t)nc;
  soundPlay(SFX_UI_MOVE);
  menuDirty = true;
}

void menuUpdate(uint32_t now) {
  uint8_t pressed = Input::takePressed();

  // 토글을 움직이면 메인 화면 표시가 바로 따라가야 확인이 된다
  static bool lastBoardMain = true;
  bool boardMain = readBoardIsMain();
  if (boardMain != lastBoardMain) { lastBoardMain = boardMain; menuDirty = true; }

  if (pressed & (1 << BTN_UP))     menuMove(+1);
  if (pressed & (1 << BTN_DOWN))   menuMove(-1);
  if (pressed & (1 << BTN_SELECT)) menuSelect();
  if (pressed & (1 << BTN_BACK))   menuBack();

  if (now - lastMenuFrameMs >= FRAME_MS) {
    lastMenuFrameMs = now;
    drawMenuStrip(now);
  }
  if (menuDirty) { menuDirty = false; drawMenuLcd(); }
}

// ---------------------------------------------------------------------------
void setup() {
  pinMode(BOARD_ID_PIN, INPUT_PULLUP);
  hasLineLeds = readBoardIsMain();   // Duel Pong 진입 시 다시 읽는다

  Input::begin();

  // 라인 LED가 없는 보드에서 176개를 다 내보내면 없는 픽셀에 데이터를 흘리며
  // show() 시간만 길어지므로(약 5.3ms → 0.12ms) 스위치 LED 4개로 줄인다.
  strip.updateLength(NUM_LEDS);
  strip.begin();
  strip.clear();
  safeShow();

  display.begin();
  soundEngineBegin(I2S_BCLK_PIN, I2S_LRC_PIN, I2S_DOUT_PIN, GAME_SOUNDS, NUM_SFX);

  Settings::begin();   // 저장된 설정을 먼저 읽고 하드웨어에 반영한다
  applyBrightness();
  applyVolume();

  bootAnimation();   // 인터럽트를 붙이기 전에 실행

  randomSeed(esp_random());

  // ESP-NOW는 Duel Pong에서만 쓰지만, 초기화는 한 번만 해 두고 게임 진입 시
  // 콜백과 피어만 붙였다 뗀다. 반복 초기화보다 안정적이다.
  WiFi.mode(WIFI_STA);
  WiFi.disconnect();
  applyChannel();   // Settings::begin()이 읽어 둔 설정값. WiFi가 뜬 뒤에야 부를 수 있다
  esp_wifi_set_ps(WIFI_PS_NONE);   // 모뎀 슬립 끔: 입력 전달 지연 스파이크 방지
  esp_now_init();

  drawBootScreen();
  delay(BOOT_LOGO_MS);

  Input::attach();
  gotoPage(P_MAIN);
}

void loop() {
  uint32_t now = millis();
  Input::poll(now);

  switch (app) {
    case APP_MENU:
      menuUpdate(now);
      break;

    case APP_SNAKE:
      SnakeInvader::update(now);
      if (SnakeInvader::wantsExit()) returnToMenu();
      break;

    case APP_SOLO:
      SoloPong::update(now);
      if (SoloPong::wantsExit()) returnToMenu();
      break;

    case APP_DUEL:
      DuelPong::update(now);
      if (DuelPong::wantsExit()) returnToMenu();
      break;
  }
}

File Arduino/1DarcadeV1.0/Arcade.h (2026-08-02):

#pragma once
/*
  ===========================================================================
  Arcade.h - 통합 스케치의 공용 계층
  ===========================================================================
  메뉴와 세 게임이 같이 쓰는 것들만 모아 둔다.
    - 하드웨어 객체(LED 스트립, LCD)
    - 스위치 입력(디바운스 + 이번 프레임에 새로 눌린 버튼)
    - 설정값(LED 밝기 / 사운드 볼륨 / ESP-NOW 채널)
    - 코트 좌표와 색 유틸

  이 파일은 .ino 한 곳에서만 include된다(게임 헤더들은 이 파일을 include한다).
  헤더에 정의까지 들어 있는 것은 사운드 데이터 헤더와 같은 이유다 - 아두이노 IDE는
  스케치 폴더의 .cpp만 컴파일하므로 번역 단위가 .ino 하나뿐이다.

  ---------------------------------------------------------------------------
  버튼 규약 (메뉴와 게임이 공유한다)
  ---------------------------------------------------------------------------
    인덱스 0 = 스위치 1 = Red   = 뒤로/취소
    인덱스 1 = 스위치 2 = Green = 위로
    인덱스 2 = 스위치 3 = Blue  = 선택
    인덱스 3 = 스위치 4 = White = 아래로
  게임 안에서는 네 개를 다른 뜻으로 쓰기도 하지만(퐁은 전부 "치기"), Red는 어디서나
  "메뉴로 돌아가기"로 남겨 둔다.
  ===========================================================================
*/

#include <Adafruit_NeoPixel.h>
#include <Adafruit_GFX.h>
#include <Adafruit_ST7735.h>
#include <SPI.h>
#include <Preferences.h>
#include <esp_wifi.h>   // applyChannel()의 esp_wifi_set_channel()

#include "SoundEngine.h"
#include "Logo1DArcade.h"

// ---------------------------------------------------------------------------
// 하드웨어
// ---------------------------------------------------------------------------
#define LED_PIN         8    // WS2815 데이터 핀(프로토콜은 WS2812 호환)

#define NUM_LEDS        176  // 스위치 내장 LED 4개 + 라인 LED 172개
#define NUM_SWITCH_LEDS 4    // index 0~3 = 스위치 1~4 내장 LED

#define FIELD_START     NUM_SWITCH_LEDS   // 필드 첫 칸(플레이어 쪽 끝) = 인덱스 4
#define FIELD_END       (NUM_LEDS - 1)    // 필드 마지막 칸(반대쪽 끝) = 인덱스 175
#define FIELD_LEN       (FIELD_END - FIELD_START + 1)   // 172

// ST7735 TFT LCD 핀 (RS=DC, SDA=MOSI, CLK=SCLK)
#define LCD_DC   9
#define LCD_CS   10
#define LCD_RST  14
#define LCD_SDA  11
#define LCD_CLK  12

#define LCD_W        160
#define LCD_H        128
#define LCD_ROTATION 3          // 0,2 = 세로(128x160) / 1,3 = 가로(160x128)
#define LCD_SPI_HZ   24000000   // 40MHz는 화면 아래쪽이 깨진다(01test_ST7735 주석 참고)
#define LCD_GREY     0x7BEF     // 라이브러리에 없는 RGB565 50% 회색

#define I2S_BCLK_PIN  42
#define I2S_LRC_PIN   41
#define I2S_DOUT_PIN  40

#define BOARD_ID_PIN  18   // 5번 토글: HIGH = 라인 LED가 달린 보드(1P), LOW = 스위치만 있는 보드(2P)

// ESP-NOW 채널은 설정 항목이 되어 아래 "설정" 절의 settingChannel로 옮겼다.

// 인덱스 = 스위치 LED 위치(0~3). 그 자리의 스위치가 물려 있는 GPIO를 적는다.
// 3번/4번 자리의 배선이 GPIO 번호 순서와 반대라 17과 16을 바꿔 넣었다.
static const uint8_t SWITCH_PINS[4] = {7, 15, 17, 16};
#define NUM_SWITCHES 4

// 버튼 역할 이름. 인덱스를 그대로 쓰지 않고 이름을 거쳐 읽도록 한다.
enum Btn : uint8_t {
  BTN_BACK   = 0,   // Red
  BTN_UP     = 1,   // Green
  BTN_SELECT = 2,   // Blue
  BTN_DOWN   = 3,   // White
};

#define DEBOUNCE_MS   30    // 스위치 채터링 무시 시간
#define FRAME_MS      16    // 스트립 렌더 주기(약 60FPS). 176픽셀 show()가 약 5.3ms
#define BOOT_LOGO_MS  3000  // 부팅 로고를 보여주는 시간

// 게임을 고르고 시작 버튼을 누른 뒤 카운트다운이 시작되기까지의 사이.
// 이 틈이 없으면 선택음과 카운트다운 첫 소리가 겹쳐 뭉개진다.
#define GAME_START_DELAY_MS 2000

// ---------------------------------------------------------------------------
// 객체
// ---------------------------------------------------------------------------
// 색 순서는 RGB다. 데이터시트상 WS2815는 GRB지만 실제 스트립은 R과 G가 반대로 나온다
// (Color(255,0,0)이 초록으로 점등). 스트립을 교체하면 여기부터 확인할 것.
Adafruit_NeoPixel strip(NUM_LEDS, LED_PIN, NEO_RGB + NEO_KHZ800);

// 하드웨어 SPI 생성자 인자 순서: (CS, DC, RST)
Adafruit_ST7735 tft = Adafruit_ST7735(LCD_CS, LCD_DC, LCD_RST);

// ST7735는 프레임버퍼를 들고 있지 않아서 화면에 직접 그리면 깜빡인다. 그래서 화면과 같은 크기의
// 캔버스에 그린 뒤 통째로 전송한다. 한 장이 40KB라 24MHz에서 약 14ms 걸리므로,
// 내용이 실제로 바뀐 순간에만 display()를 부른다.
class Lcd : public GFXcanvas16 {
public:
  Lcd() : GFXcanvas16(LCD_W, LCD_H) {}
  void begin() {
    SPI.begin(LCD_CLK, -1, LCD_SDA, LCD_CS);   // MISO는 LCD가 쓰지 않아 -1
    tft.initR(INITR_BLACKTAB);
    tft.setSPISpeed(LCD_SPI_HZ);
    tft.setRotation(LCD_ROTATION);
    tft.fillScreen(ST77XX_BLACK);
  }
  void clearDisplay() { fillScreen(ST77XX_BLACK); }
  void display() { tft.drawRGBBitmap(0, 0, getBuffer(), LCD_W, LCD_H); }
};

Lcd display;

// 5번 토글을 지금 읽는다. HIGH = 라인 LED가 달린 보드(Duel Pong의 1P).
// 부팅 때 한 번만 읽으면 메뉴에서 토글을 바꿔도 반영되지 않아 재부팅해야 하므로,
// 값이 필요한 시점마다 이 함수로 읽는다.
bool readBoardIsMain() { return digitalRead(BOARD_ID_PIN) == HIGH; }

// 이 보드에 라인 LED가 물려 있는가. 게임에 들어갈 때 readBoardIsMain()으로 갱신한다.
//
// 이 값은 Duel Pong의 1P/2P 역할을 정하는 데에만 쓴다. 렌더링은 이 값을 보지 않고 늘
// 스트립 전체를 그린다. 토글이 반대로 놓여 있다고 해서 라인 LED가 통째로 죽으면
// 메뉴에서는 원인을 알 방법이 없기 때문이다. 없는 픽셀에 데이터를 흘리는 비용은
// show() 시간뿐이고(약 5.3ms), 스위치만 있는 보드는 어차피 그릴 게 거의 없다.
bool hasLineLeds = true;

// ---------------------------------------------------------------------------
// 사운드
// ---------------------------------------------------------------------------
// 세 게임과 메뉴가 쓰는 소리를 한 표에 모았다. 실제 클립 배열은 .ino에 있다.
// 이름은 "어떤 소리인가"가 아니라 "언제 나는가" 기준이다.
enum SfxId : uint8_t {
  SFX_UI_MOVE = 0,    // 메뉴 커서 이동
  SFX_UI_SELECT,      // 메뉴 선택
  SFX_UI_BACK,        // 뒤로 가기
  SFX_READY_BOTH,     // 양쪽 플레이어가 다 준비됨(2P 전용)
  SFX_COUNTDOWN,      // 카운트다운 한 칸
  SFX_START,          // START
  SFX_SERVE,          // 서브 출발
  SFX_HIT_GREEN,      // 초록 영역에서 반사
  SFX_HIT_YELLOW,     // 노랑 영역에서 반사
  SFX_HIT_RED,        // 빨강 영역에서 반사
  SFX_CPU_HIT,        // CPU가 받아침
  SFX_MISS,           // 공을 놓침
  SFX_MISS_OPPONENT,  // 상대가 놓침
  SFX_SHOOT,          // 총알 발사
  SFX_BULLET_HIT,     // 총알 명중 - 색이 맞음
  SFX_BULLET_MISS,    // 총알 명중 - 색이 틀림
  SFX_SNAKE_STEP,     // 지렁이가 한 칸 전진
  SFX_LEVEL_CLEAR,    // 레벨 클리어
  SFX_WIN,            // 승리
  SFX_GAME_OVER,      // 게임 오버
  NUM_SFX
};

// ---------------------------------------------------------------------------
// 설정 (설정 메뉴에서 바꾸고 모든 게임이 따른다)
// ---------------------------------------------------------------------------
// 밝기와 볼륨은 단계로 들고 있다가 하드웨어 값으로 변환한다. 화면에 막대로 보여주기 쉽고,
// NVS에 저장할 때도 작은 정수 하나면 된다.
#define SETTING_STEPS     10    // 밝기/볼륨 공통 단계 수 (0 = 최소)
#define BRIGHTNESS_MIN    20    // 0단계에서의 스트립 밝기(완전히 끄지는 않는다)
#define BRIGHTNESS_MAX   200    // 최고 단계에서의 스트립 밝기

// ESP-NOW 채널. 두 보드가 같은 값이어야 Duel Pong에서 서로 보인다.
// 밝기/볼륨과 달리 단계가 아니라 채널 번호 그대로라서 범위를 따로 둔다.
// 주변 공유기와 겹치면 패킷이 밀리므로 현장에서 바꿀 수 있게 설정 항목으로 뺐다.
#define CHANNEL_MIN       1
#define CHANNEL_MAX      13    // 국내 2.4GHz 허용 범위
#define CHANNEL_DEFAULT   1

// 기본값은 한가운데. 단계 수가 바뀌어도 체감 기본이 유지되도록 절반 지점으로 둔다.
uint8_t settingBrightness = SETTING_STEPS / 2;   // 0 ~ SETTING_STEPS
uint8_t settingVolume     = SETTING_STEPS / 2;   // 0 ~ SETTING_STEPS (0 = 무음)
uint8_t settingChannel    = CHANNEL_DEFAULT;     // CHANNEL_MIN ~ CHANNEL_MAX

void applyBrightness() {
  uint16_t span = BRIGHTNESS_MAX - BRIGHTNESS_MIN;
  uint8_t v = (uint8_t)(BRIGHTNESS_MIN + (uint32_t)span * settingBrightness / SETTING_STEPS);
  strip.setBrightness(v);
}

void applyVolume() {
  soundSetGain((uint16_t)((uint32_t)SOUND_GAIN_UNITY * settingVolume / SETTING_STEPS));
}
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

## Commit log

2026-07-08 README.md 파일 추가: ws2812 라인 LED를 사용한 1D 아케이드 게임기 제작 프로젝트 설명
2026-07-08 Add new sound effects for explosion, power-up, and shots
    - Added explosion sound effect (explosion01.wav)
    - Added power-up sound effect (powerUp.wav)
    - Added shot sound effects (shot1.wav and shot2.wav)
2026-07-10 Nokia 5110 LCD 테스트 코드 추가
2026-07-17 테스트 코드 추가: Nokia 5110 LCD 및 스위치와 LED 제어 기능 구현
2026-07-18 Add audio files and partition configuration for LED switch project
    - Added explosion01.wav, powerUp.wav, shot1.wav, and shot2.wav audio files to the project.
    - Created partitions.csv to define memory layout for the firmware, including NVS, OTA data, application partitions, and SPIFFS.
    [partitions.csv]
2026-07-19 게임 설명 및 알고리즘 추가: 1D 아케이드 게임의 확정 게임 목록과 알고리즘 정리
2026-07-22 게임 로직 문서 및 Snake Invader 테스트 코드 추가
2026-07-23 Add new sound effects for laser and coin pickup
    - Added laser sound effect (laser.wav) to enhance gameplay experience.
    - Added two coin pickup sound effects (pickupCoin01.wav and pickupCoin02.wav) for improved audio feedback when collecting items.
2026-07-24 1P/2P 통신 처리 추가 및 게임 로직 문서 업데이트
2026-07-29 Refactor and enhance various test codes
    - Updated 03SwitchandLEDtest to improve LED control and switch handling with debounce logic.
    - Added MAX98357A I2S hardware test code for simple sine wave playback.
    - Improved 05test_wavplay with clearer comments and structure.
    - Enhanced 06test_switch_LED_WAV for better LED handling and added safeShow function for WS2815 timing stability.
    - Removed obsolete test_nokia5110 code.
    - Updated test_snakeinvader to clarify LED configurations and improve game logic.
    - Added initial documentation for ESP-NOW communication setup in 07test_espnow.
    - Cleaned up markdown documentation for clarity and added new test code descriptions.
    [02test_switch.ino, 03SwitchandLEDtest.ino, 04test_max98357.ino]
2026-07-30 Implement ESP-NOW communication for 1P and 2P arcade game with LCD display integration 사운드 재생방식 변경.
    [partitions.csv]
2026-08-01 1P/2P 역할 전환을 위한 BOARD_ID_PIN 읽기 로직 개선 및 메인 메뉴에 상태 표시 추가
2026-08-02 Refactor code structure for improved readability and maintainability
    [Box.step, Box_Cover.step, Connector_Cover_1stripe.step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]
2026-09-06 총알 색 불일치 시 꼬리 길이 증가 및 게임 오버 메시지 개선
2026-09-06 게임 오버 메시지 표시 기능 추가 및 관련 코드 정리
2026-09-06 게임 오버 상태 추가 및 화면 유지 시간 설정
